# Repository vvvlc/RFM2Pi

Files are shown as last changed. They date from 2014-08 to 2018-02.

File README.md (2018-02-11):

# RFM2Pi
======



## RFM12B / RFM69CW to Raspberry Pi board

With the addition of an RFM12Pi expansion board to receive data via wireless from other [OpenEnergyMonitor modules](http://openenergymonitor.org/emon/Modules) such as an emonTx energy and temperature monitoring node or an emonGLCD display. A Raspberry Pi used to forward data to an emoncms sever or/and log data locally to a localy instance of Emoncms server running on the Pi.

# Hardware Design
For hardware designs see https://github.com/openenergymonitor/Hardware/tree/master/RFM2Pi

## Documentation Overview
http://openenergymonitor.org/emon/emonbase/raspberrypi

## Technial Wiki
http://wiki.openenergymonitor.org/index.php?title=RFM12Pi_V2

### The RFM12Pi is sold through the OpenEnergyMonitor shop:
http://shop.openenergymonitor.com/raspberry-pi/

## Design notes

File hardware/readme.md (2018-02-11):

## RFM2Pi

A collaboration between Martin Harizanov and OpenEnergyMonitor. Martin's origional repo: https://github.com/mharizanov/RFM2Pi/

### Schematic and board files: 

See board folder

### Schematic

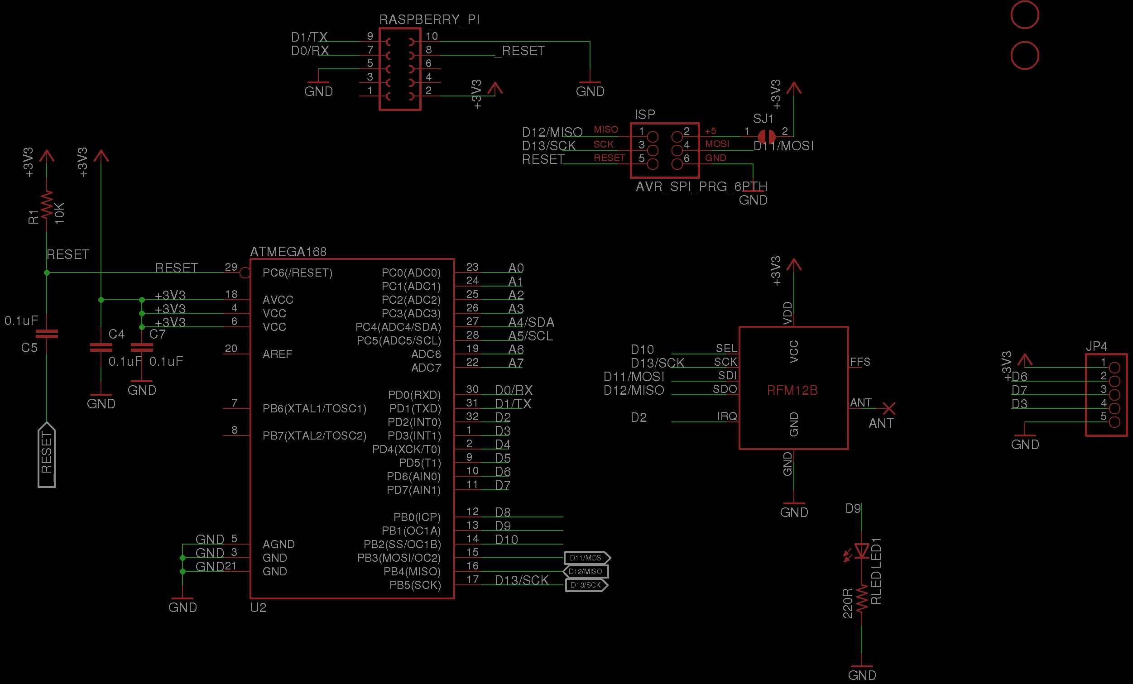
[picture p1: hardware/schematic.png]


Download schematic: [https://github.com/openenergymonitor/RFM2Pi/blob/master/board/v2/RFM2Pi_v2.6.sch](https://github.com/openenergymonitor/RFM2Pi/blob/master/board/v2/RFM2Pi_v2.6.sch)

### Board

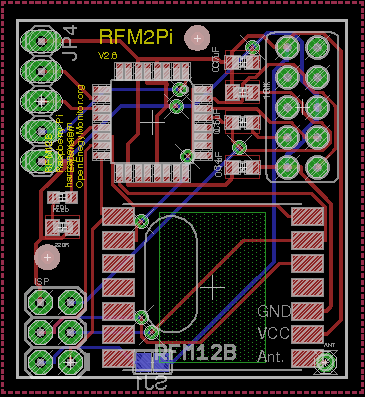
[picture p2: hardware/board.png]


Download board: [https://github.com/openenergymonitor/RFM2Pi/blob/master/board/v2/RFM2Pi_v2.6.brd](https://github.com/openenergymonitor/RFM2Pi/blob/master/board/v2/RFM2Pi_v2.6.brd)

### Open Hardware

Hardware designs (schematics and CAD) files are licensed under the [Creative Commons Attribution-ShareAlike 3.0 Unported License](http://creativecommons.org/licenses/by-sa/3.0/) and follow the terms of the [OSHW (Open-source hardware) Statement of Principles 1.0.](http://freedomdefined.org/OSHW)

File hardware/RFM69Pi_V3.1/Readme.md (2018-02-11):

## RFM2Pi V3

Updated RFM12B / RFM69CW expansion board for the Raspberry Pi with ATmega328 I/O broken out. Developed with help from [Ken Boak](http://sustburbia.blogspot.co.uk/) 

http://wiki.openenergymonitor.org/index.php?title=RFM69Pi_V3

### Board

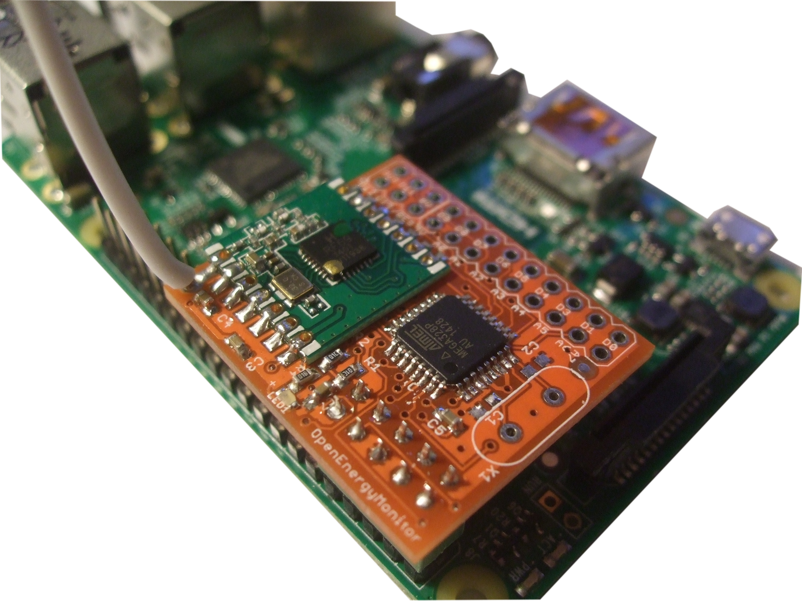
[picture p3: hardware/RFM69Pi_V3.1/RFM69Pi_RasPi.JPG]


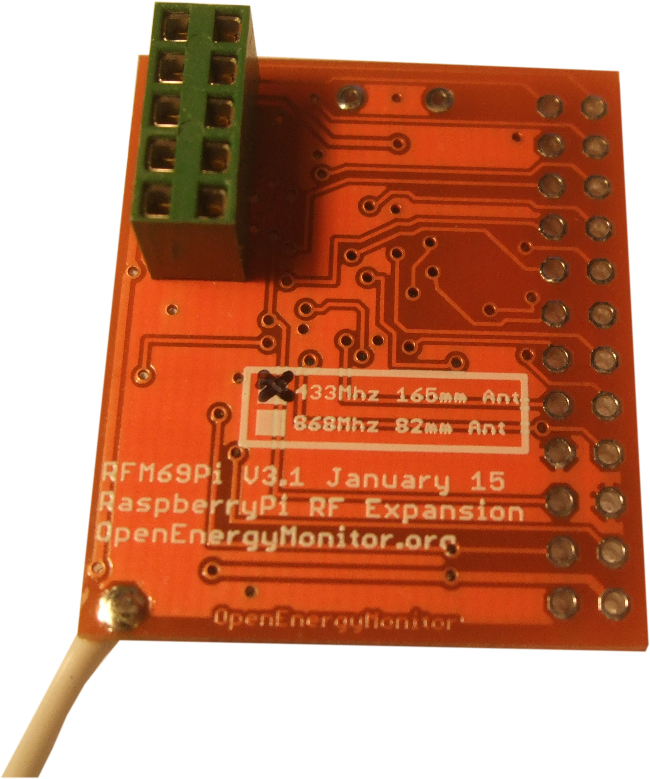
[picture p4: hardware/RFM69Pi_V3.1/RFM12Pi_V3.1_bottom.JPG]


### Schematic and board: 

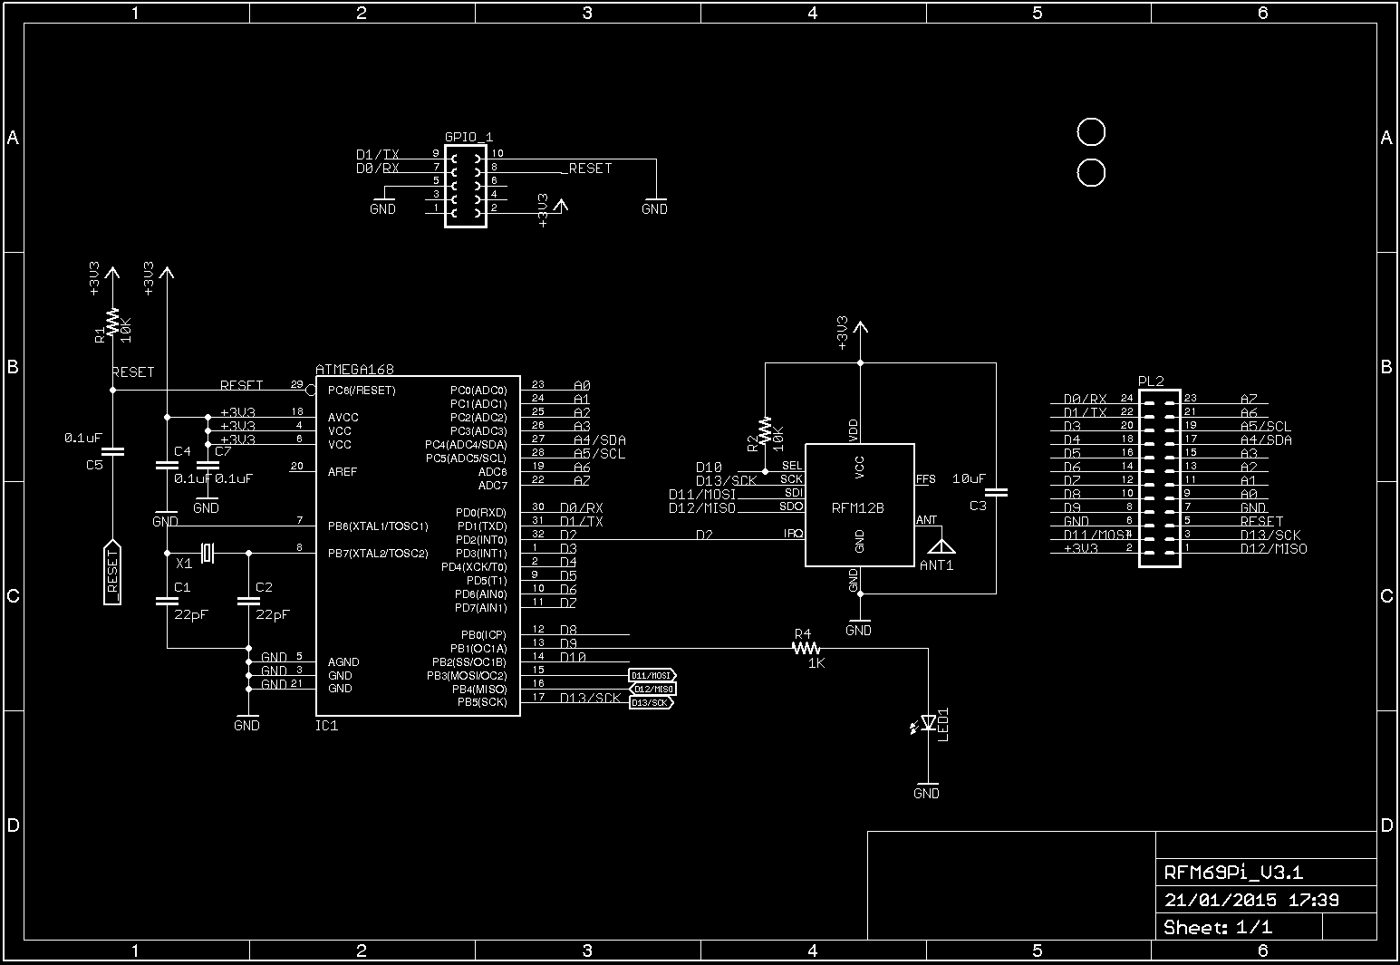
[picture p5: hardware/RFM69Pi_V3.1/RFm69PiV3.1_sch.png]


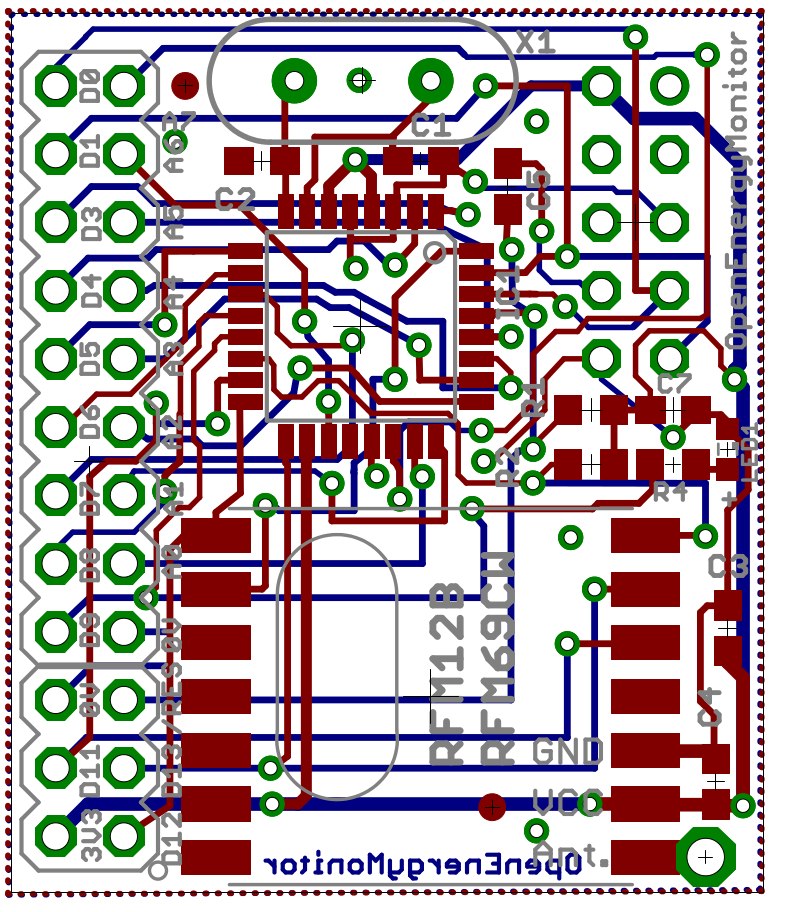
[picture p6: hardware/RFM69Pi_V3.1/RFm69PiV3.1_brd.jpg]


### Open Hardware

Hardware designs (schematics and CAD) files are licensed under the [Creative Commons Attribution-ShareAlike 3.0 Unported License](http://creativecommons.org/licenses/by-sa/3.0/) and follow the terms of the [OSHW (Open-source hardware) Statement of Principles 1.0.](http://freedomdefined.org/OSHW)

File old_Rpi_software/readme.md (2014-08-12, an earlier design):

old RFM12Pi software, emonHub is now used as our current (Aug 2014) RFM12Pi interface software

https://github.com/emonhub

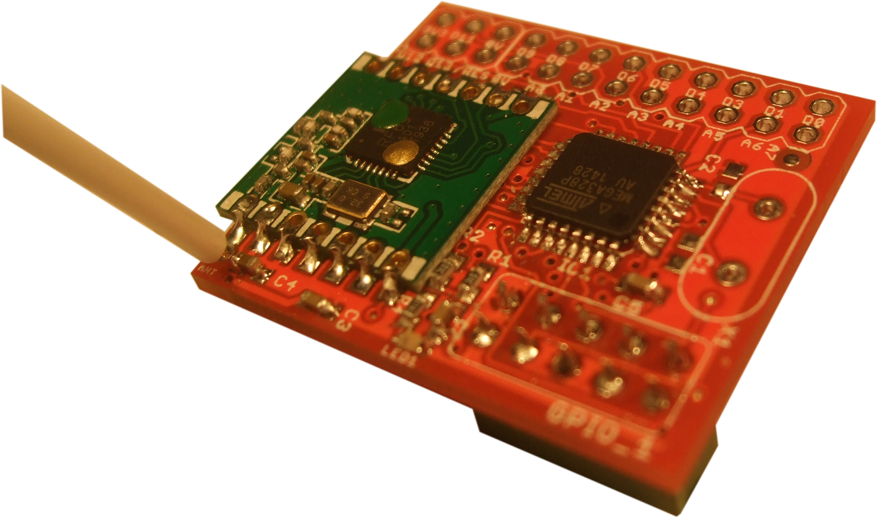
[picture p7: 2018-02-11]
hardware/RFM69Pi_V3.1/RFM12Pi_V3.1_top_side.JPG

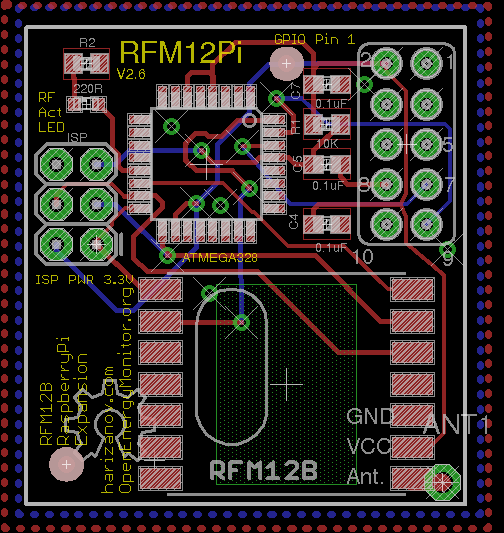
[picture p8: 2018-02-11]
hardware/RFM12Pi_V2.6/RFM12Pi_V2.6_brd.png

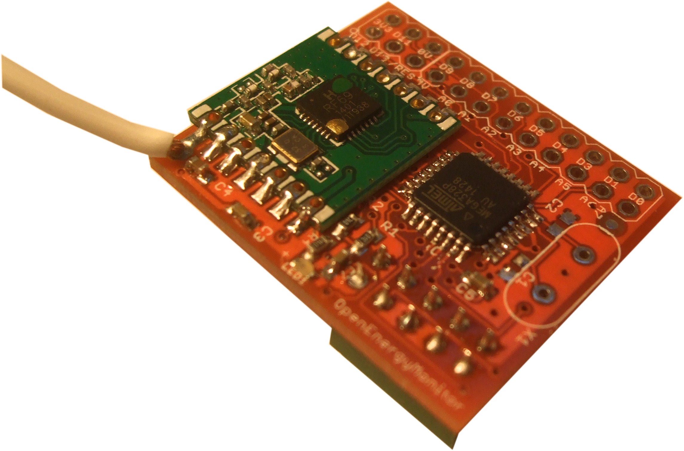
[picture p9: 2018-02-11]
hardware/RFM69Pi_V3.1/RFM12Pi_V3.1_top_side2.JPG

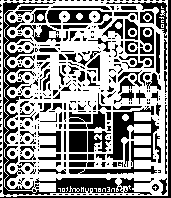
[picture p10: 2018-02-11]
hardware/RFM69Pi_V3.1/RFm69PiV3.1_brd_white.png

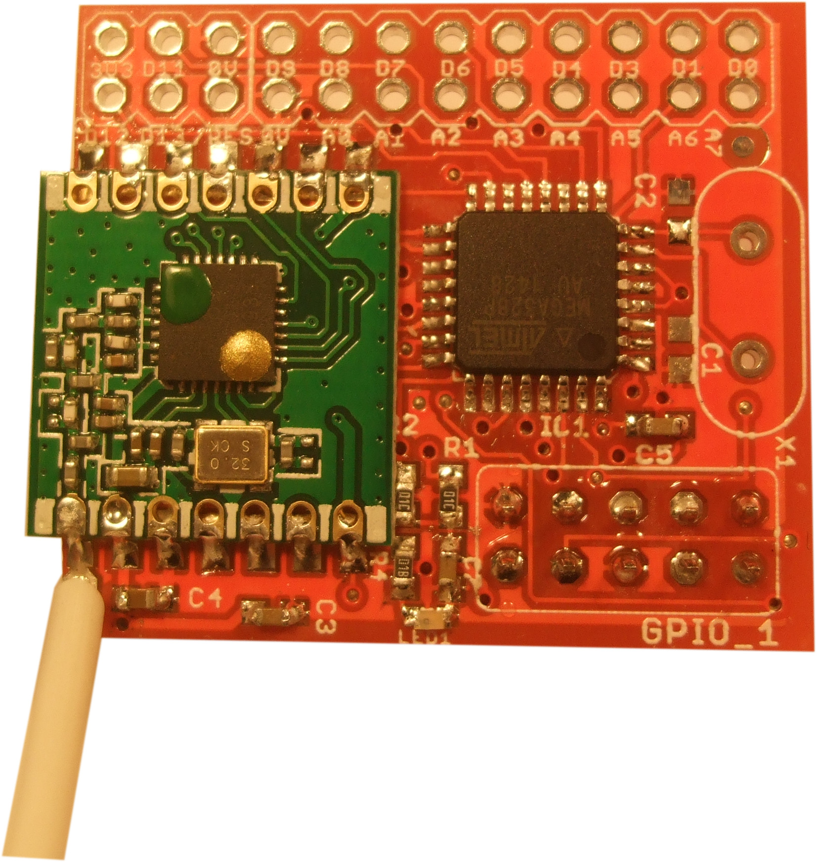
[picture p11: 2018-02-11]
hardware/RFM69Pi_V3.1/RFM12Pi_V3.1_top.JPG

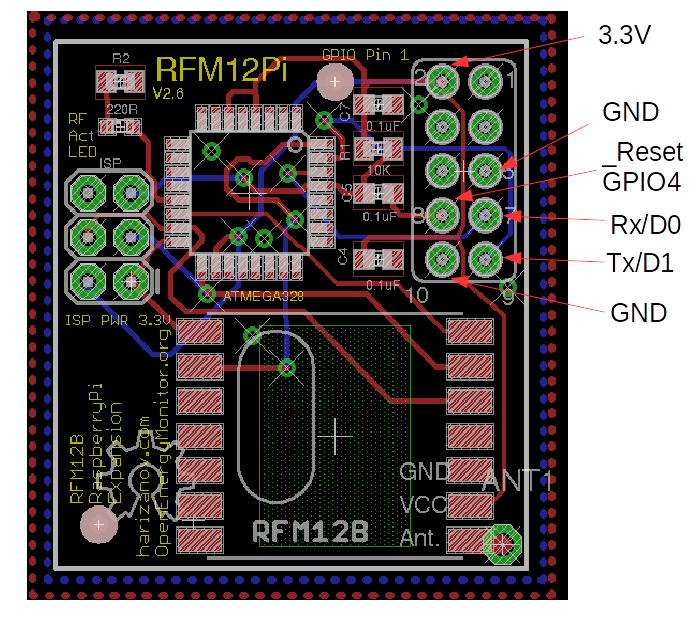
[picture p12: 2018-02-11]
hardware/RFM12Pi_V2.6/RFM12Pi_V1.6_pinout_brd.png

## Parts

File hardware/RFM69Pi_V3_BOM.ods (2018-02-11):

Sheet: DMT
 |  | RFM69Pi V3.1 1000PCS Feb 2015 |  |  |  |  | Megni / OpenEnergyMonitor – Glyn Hudson
Line No | Qty per | Parts | Value | Package | Order Qty | RS Part | Manufact | Manufact Part | Price Each | Line Price
 | SMT
1 | 3 | C4, C5, C7 | 100nF | 0603 | 3000 | 698-3320P | AVX | 0603YC104KAT2A | £0.01 | £21.00
2 | 2 | R1, R2 | 10K | 0603 | 2000 | 810-2094P | Panasonic | ERJ3RBD1002V | £0.01 | £18.00
3 | 1 | C3 | 10uF | 0603 | 1000 | 723-5543P | Murata | GRM188R60J106ME47D | £0.05 | £53.00
4 | 1 | R4 | 1K | R0603 | 1000 | 740-8791P | Bourns | CR0603-FX-1001ELF | £0.01 | £7.00
5 | 1 | LED1 | Red 1.85V | 0603 | 1000 | 654-5802P | OSRAM | LH Q974 | £0.02 | £24.00
6 | 1 | IC1 |  | TQFP32-08 | 1000 | 696-3092P | Atmel | ATMEGA328P-AU | £1.13 | £1,130.00
7 | 1 | X1 / GPIO_1 | 2 x 5 | 2.54mm female header | 1000 | 495-8644P | TE Connectivity | 215307-5 | 0.263 | £263.00 | INSERTED FROM REAR – SOLDERED ON TOP
 |  |  |  |  |  |  |  | Total | £1.49 | £1,253.00

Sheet: Megni Proc
Through Hole
800 | ANT | 165mm | 433mhz | 165mm 433Mhz / 82mm 868Mhz | PROCURED BY DAVID
200 | ANT | 82mm | 868mhz
Free issue by Megni – need to be placed but not procured
800 | RFM69CW | 433Mhz
200 | RFM69CW | 868Mhz
 | Exported from RFM69Pi CAD 27th Dec 2014

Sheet: BOM for Kaizen
 | RFM69Pi V3.1 1000PCS Feb 2015 |  |  |  |  | Megni / OpenEnergyMonitor – Glyn Hudson
Line No | Qty per | Parts | Value | Package | Order Qty | RS Part | Manufact | Manufact Part
1 | 3 | C4, C5, C7 | 100nF | 0603 | 3000 | 698-3320P | AVX | 0603YC104KAT2A
2 | 2 | R1, R2 | 10K | 0603 | 2000 | 810-2094P | Panasonic | ERJ3RBD1002V
3 | 1 | C3 | 10uF | 0603 | 1000 | 723-5543P | Murata | GRM188R60J106ME47D
4 | 1 | R4 | 1K | R0603 | 1000 | 740-8791P | Bourns | CR0603-FX-1001ELF
5 | 1 | LED1 | Red 1.85V | 0603 | 1000 | 654-5802P | OSRAM | LH Q974
6 | 1 | IC1 |  | TQFP32-08 | 1000 | 696-3092P | Atmel | ATMEGA328P-AU
7 | 1 | X1 / GPIO_1 | 2 x 5 | 2.54mm female header | 1000 | 495-8644P | TE Connectivity | 215307-5
8 | 1 | RFM69CW | 433Mhz | SMT | 800 | N/A | Hope RF | RFM69CW433
8 | 1 | RFM69CW | 868Mhz | SMT | 200 | N/A | Hope RF | RFM69CW868
9 | 1 | ANT | 165mm | 433mhz | 800 | Farnell 2343921 | Pro Wire | 4161 – PROCURED BY KAIZEN
9 | 1 | ANT | 82mm | 868mhz | 200 | Farnell 2343921 | Pro Wire | 4161 – PROCURED BY KAIZEN
 | updated 4th Feb 2015
 | RS Quote A1001654264
 | RS order 127992627 3rd Feb 2015

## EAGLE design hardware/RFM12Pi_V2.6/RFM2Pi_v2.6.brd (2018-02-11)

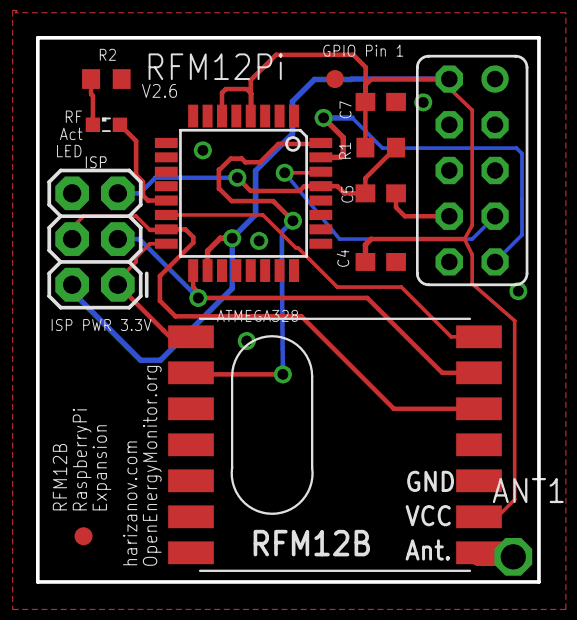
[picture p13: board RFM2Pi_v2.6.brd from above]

Board: 2 copper layers, 27.8 x 30.2 mm, 14 parts (1 on the bottom side), 14 nets.

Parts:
ANT1: PAD-01
C4, C5, C7: 0.1uF; C0603
ISP: AVR_SPI_PRG_6PTH; 2X3
LED: SML0603
R1: 10K; R0603
R2: 220R; R0603
RASPBERRY_PI: FE05-2
RFM12B: RFM12B
U2: ATMEGA168; TQFP32-08
U$1, U$2: FIDUCIAL; FIDUCIAL_1MM
U$4: OSHW_6X200_NOTEXT

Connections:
+3V3: C4.1, C7.1, ISP.2, R1.2, RASPBERRY_PI.2, RFM12B.VDD, U2.4, U2.6, U2.18
D0/RX: RASPBERRY_PI.7, U2.30
D1/TX: RASPBERRY_PI.9, U2.31
D2: RFM12B.IRQ, U2.32
D9: LED.A, U2.13
D10: RFM12B.SEL, U2.14
D11/MOSI: ISP.4, RFM12B.SDI, U2.15
D12/MISO: ISP.1, RFM12B.SDO, U2.16
D13/SCK: ISP.3, RFM12B.SCK, U2.17
GND: C4.2, C7.2, ISP.6, R2.1, RASPBERRY_PI.5, RASPBERRY_PI.10, RFM12B.GND, U2.3, U2.5, U2.21
unnamed: LED.C, R2.2
unnamed: ANT1.1, RFM12B.ANT
RESET: C5.2, ISP.5, R1.1, U2.29
_RESET: C5.1, RASPBERRY_PI.8

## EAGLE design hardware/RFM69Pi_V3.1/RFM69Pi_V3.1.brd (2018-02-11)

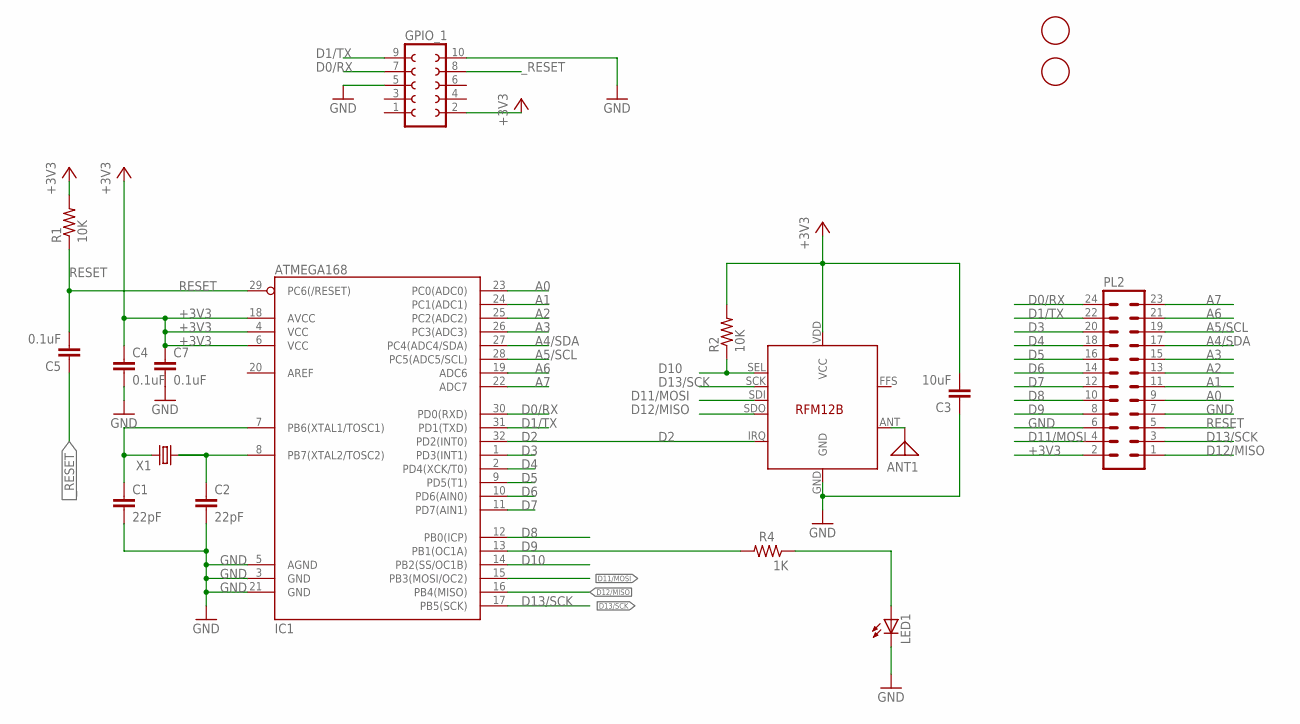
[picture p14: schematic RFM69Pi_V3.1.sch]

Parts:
ANT1: ANTENNA; PAD-01
C1, C2: 22pF; C0603
C3: 10uF; C0603
C4, C5, C7: 0.1uF; C0603
GPIO_1: FE05-2
IC1: ATMEGA168; TQFP32-08
LED1: LEDSML0603; SML0603
PL2: MA12-2
R1, R2: 10K; R0603
R4: 1K; R0603
RFM12B-RFM69CW: RFM12B
U$1, U$2: FIDUCIAL; FIDUCIAL_1MM
X1: CRYSTALHC49US; HC49US

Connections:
+3V3: C3.2, C4.1, C7.1, GPIO_1.2, IC1.4 (VCC), IC1.6 (VCC), IC1.18 (AVCC), PL2.2, R1.2, R2.2, RFM12B-RFM69CW.VDD (VCC)
A0: IC1.23 (PC0(ADC0)), PL2.9
A1: IC1.24 (PC1(ADC1)), PL2.11
A2: IC1.25 (PC2(ADC2)), PL2.13
A3: IC1.26 (PC3(ADC3)), PL2.15
A4/SDA: IC1.27 (PC4(ADC4/SDA)), PL2.17
A5/SCL: IC1.28 (PC5(ADC5/SCL)), PL2.19
A6: IC1.19 (ADC6), PL2.21
A7: IC1.22 (ADC7), PL2.23
D0/RX: GPIO_1.7, IC1.30 (PD0(RXD)), PL2.24
D1/TX: GPIO_1.9, IC1.31 (PD1(TXD)), PL2.22
D2: IC1.32 (PD2(INT0)), RFM12B-RFM69CW.IRQ
D3: IC1.1 (PD3(INT1)), PL2.20
D4: IC1.2 (PD4(XCK/T0)), PL2.18
D5: IC1.9 (PD5(T1)), PL2.16
D6: IC1.10 (PD6(AIN0)), PL2.14
D7: IC1.11 (PD7(AIN1)), PL2.12
D8: IC1.12 (PB0(ICP)), PL2.10
D9: IC1.13 (PB1(OC1A)), PL2.8, R4.2
D10: IC1.14 (PB2(SS/OC1B)), R2.1, RFM12B-RFM69CW.SEL
D11/MOSI: IC1.15 (PB3(MOSI/OC2)), PL2.4, RFM12B-RFM69CW.SDI
D12/MISO: IC1.16 (PB4(MISO)), PL2.1, RFM12B-RFM69CW.SDO
D13/SCK: IC1.17 (PB5(SCK)), PL2.3, RFM12B-RFM69CW.SCK
GND: C1.2, C2.2, C3.1, C4.2, C7.2, GPIO_1.5, GPIO_1.10, IC1.3 (GND), IC1.5 (AGND), IC1.21 (GND), LED1.C, PL2.6, PL2.7, RFM12B-RFM69CW.GND
unnamed: C1.1, IC1.7 (PB6(XTAL1/TOSC1)), X1.2
unnamed: C2.1, IC1.8 (PB7(XTAL2/TOSC2)), X1.1
unnamed: LED1.A, R4.1
unnamed: ANT1.1, RFM12B-RFM69CW.ANT
RESET: C5.2, IC1.29 (PC6(/RESET)), PL2.5, R1.1
_RESET: C5.1, GPIO_1.8

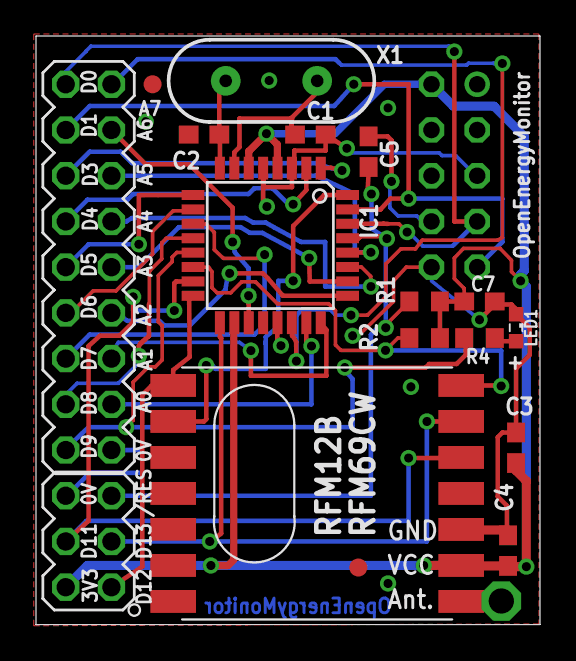
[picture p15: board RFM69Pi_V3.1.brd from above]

Board: 2 copper layers, 28.0 x 32.7 mm, 18 parts (0 on the bottom side), 30 nets.

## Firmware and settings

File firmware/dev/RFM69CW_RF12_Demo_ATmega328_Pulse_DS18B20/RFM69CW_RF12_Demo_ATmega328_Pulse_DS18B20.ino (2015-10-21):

//RFM12Pi V2 with RFM69CW Firmware 
//Based on JCW RF12 Demo: https://github.com/jcw/jeelib/tree/master/examples/RF12/RF12demo
//Edited for RFM12Pi and emonPi operation June 2014 by Glyn Hudson and Trystan Lea 
//http://OpenEnergyMonitor.org
//https://github.com/openenergymonitor/RFM2Pi

// V1.3 July 15 - add RF trace mode debug and fix node ID isse, merge pb66 pull requests 
  // https://github.com/openenergymonitor/RFM2Pi/pull/2
  // https://github.com/openenergymonitor/RFM2Pi/pull/4

// Version V1.0 - Nov 2014
// * 433Mhz default frequency, 15 default node ID

// V0.9 June 2014
// * 210 default network group
// * activity LED to light on startup and each time packet is received 

//--------------------------------------------------------------------------------------------------------------------------------------------

//------------------------------------------------------------------------
typedef struct {
    int pulsepower;
    unsigned long pulsecount; 
    int temp[6];  	                                      
} Payload;
Payload rfm2pi;
unsigned long lastdatasend = 0;

unsigned long pulsedebouncetime = 0;
unsigned long pulsetime = 0;
unsigned long lastpulsetime = 0;
unsigned long lastsentpulse = 0;
byte pulse_nodeid = 15;
int pulses_per_wh = 1;

// minimum width of interrupt pulse (default pulse output meters = 100ms)
const byte min_pulsewidth= 110;

//------------------------------------------------------------------------

/// @dir RF12demo
/// Configure some values in EEPROM for easy config of the RF12 later on.
// 2009-05-06 <jc@wippler.nl> http://opensource.org/licenses/mit-license.php

// this version adds flash memory support, 2009-11-19
// Adding frequency features, author JohnO, 2013-09-05
// Major EEPROM format change, refactoring, and cleanup for v12, 2014-02-13

#define RF69_COMPAT 1 // define this to use the RF69 driver i.s.o. RF12

#include <JeeLib.h>
#include <util/crc16.h>
#include <avr/eeprom.h>
#include <avr/pgmspace.h>
#include <util/parity.h>

#define MAJOR_VERSION RF12_EEPROM_VERSION // bump when EEPROM layout changes
#define MINOR_VERSION 2                   // bump on other non-trivial changes
#define VERSION "[RF12demo.13]"           // keep in sync with the above

#if defined(__AVR_ATtiny84__) || defined(__AVR_ATtiny44__)
#define TINY        1
#define SERIAL_BAUD 38400   // can only be 9600 or 38400
#define DATAFLASH   0       // do not change
#undef  LED_PIN             // do not change
#define rf12_configDump()   // disabled
#else
#define TINY        0
#define SERIAL_BAUD 38400   // max baud for 8Mhz RFM12Pi http://openenergymonitor.org/emon/node/6244/
#define DATAFLASH   0       // set to 0 for non-JeeLinks, else 4/8/16 (Mbit)
#define LED_PIN     9       // activity LED, comment out to disable
#endif

/// Save a few bytes of flash by declaring const if used more than once.
const char INVALID1[] PROGMEM = "\rInvalid\n";
const char INITFAIL[] PROGMEM = "config save failed\n";

#if RF69_COMPAT
  byte trace_mode = 0;
#endif

#if TINY
// Serial support (output only) for Tiny supported by TinyDebugSerial
// http://www.ernstc.dk/arduino/tinycom.html
// 9600, 38400, or 115200
// hardware\jeelabs\avr\cores\tiny\TinyDebugSerial.h Modified to
// moveTinyDebugSerial from PB0 to PA3 to match the Jeenode Micro V3 PCB layout
// Connect Tiny84 PA3 to USB-BUB RXD for serial output from sketch.
// Jeenode AIO2
//
// With thanks for the inspiration by 2006 David A. Mellis and his AFSoftSerial
// code. All right reserved.
// Connect Tiny84 PA2 to USB-BUB TXD for serial input to sketch.
// Jeenode DIO2
// 9600 or 38400 at present.

#if SERIAL_BAUD == 9600
#define BITDELAY 54          // 9k6 @ 8MHz, 19k2 @16MHz
#endif
#if SERIAL_BAUD == 38400
#define BITDELAY 11         // 38k4 @ 8MHz, 76k8 @16MHz
#endif

#define _receivePin 8
static int _bitDelay;
static char _receive_buffer;
static byte _receive_buffer_index;

ISR (PCINT0_vect) {
  char i, d = 0;
  if (digitalRead(_receivePin))       // PA2 = Jeenode DIO2
    return;             // not ready!
  whackDelay(_bitDelay - 8);
  for (i=0; i<8; i++) {
    whackDelay(_bitDelay*2 - 6);    // digitalread takes some time
    if (digitalRead(_receivePin)) // PA2 = Jeenode DIO2
      d |= (1 << i);
  }
  whackDelay(_bitDelay*2);
  if (_receive_buffer_index)
    return;
  _receive_buffer = d;                // save data
  _receive_buffer_index = 1;  // got a byte
}

// TODO: replace with code from the std avr libc library:
//  http://www.nongnu.org/avr-libc/user-manual/group__util__delay__basic.html
void whackDelay (word delay) {
  byte tmp=0;

  asm volatile("sbiw      %0, 0x01 \n\t"
    "ldi %1, 0xFF \n\t"
    "cpi %A0, 0xFF \n\t"
    "cpc %B0, %1 \n\t"
    "brne .-10 \n\t"
: 
    "+r" (delay), "+a" (tmp)
: 
    "0" (delay)
    );
}

static byte inChar () {
  byte d;
  if (! _receive_buffer_index)
    return -1;
  d = _receive_buffer; // grab first and only byte
  _receive_buffer_index = 0;
  return d;
}

#endif

static unsigned long now () {
  // FIXME 49-day overflow
  return millis() / 1000;
}

static void activityLed (byte on) {
#ifdef LED_PIN
  pinMode(LED_PIN, OUTPUT);
  digitalWrite(LED_PIN, on);
#endif
}

static void printOneChar (char c) {
  Serial.print(c);
}

/// @details
/// For the EEPROM layout, see http://jeelabs.net/projects/jeelib/wiki/RF12demo
/// Useful url: http://blog.strobotics.com.au/2009/07/27/rfm12-tutorial-part-3a/

// RF12 configuration area
typedef struct {
  byte nodeId;            // used by rf12_config, offset 0
  byte group;             // used by rf12_config, offset 1
  byte format;            // used by rf12_config, offset 2
byte hex_output   :
  2;   // 0 = dec, 1 = hex, 2 = hex+ascii
byte collect_mode :
  1;   // 0 = ack, 1 = don't send acks
byte quiet_mode   :
  1;   // 0 = show all, 1 = show only valid packets
byte spare_flags  :
  4;
  word frequency_offset;  // used by rf12_config, offset 4
  byte pad[RF12_EEPROM_SIZE-8];
  word crc;
} 
RF12Config;

static RF12Config config;
static char cmd;
static word value;
static byte stack[RF12_MAXDATA+4], top, sendLen, dest;
static byte testCounter;

static void showNibble (byte nibble) {
  char c = '0' + (nibble & 0x0F);
  if (c > '9')
    c += 7;
  Serial.print(c);
}

static void showByte (byte value) {
  if (config.hex_output) {
    showNibble(value >> 4);
    showNibble(value);
  } 
  else
    Serial.print((word) value);
}

static word calcCrc (const void* ptr, byte len) {
  word crc = ~0;
  for (byte i = 0; i < len; ++i)
    crc = _crc16_update(crc, ((const byte*) ptr)[i]);
  return crc;
}

static void loadConfig () {
  // eeprom_read_block(&config, RF12_EEPROM_ADDR, sizeof config);
  // this uses 166 bytes less flash than eeprom_read_block(), no idea why
  for (byte i = 0; i < sizeof config; ++ i)
    ((byte*) &config)[i] = eeprom_read_byte(RF12_EEPROM_ADDR + i);
}

static void saveConfig () {
  config.format = MAJOR_VERSION;
  config.crc = calcCrc(&config, sizeof config - 2);
  // eeprom_write_block(&config, RF12_EEPROM_ADDR, sizeof config);
  // this uses 170 bytes less flash than eeprom_write_block(), no idea why
  eeprom_write_byte(RF12_EEPROM_ADDR, ((byte*) &config)[0]);
  for (byte i = 0; i < sizeof config; ++ i)
    eeprom_write_byte(RF12_EEPROM_ADDR + i, ((byte*) &config)[i]);

  if (rf12_configSilent())
    rf12_configDump();
  else
    showString(INITFAIL);
}

static byte bandToFreq (byte band) {
  return band == 4 ? RF12_433MHZ : band == 8 ? RF12_868MHZ : band == 9 ? RF12_915MHZ : 0;
}

// - - - - - - - - - - - - - - - - - - - - - - - - - - - - - - - - - - - - - - -
// OOK transmit code

#if RF69_COMPAT // not implemented in RF69 compatibility mode
static void fs20cmd(word house, byte addr, byte cmd) {
}
static void kakuSend(char addr, byte device, byte on) {
}
#else

// Turn transmitter on or off, but also apply asymmetric correction and account
// for 25 us SPI overhead to end up with the proper on-the-air pulse widths.
// With thanks to JGJ Veken for his help in getting these values right.
static void ookPulse(int on, int off) {
  rf12_onOff(1);
  delayMicroseconds(on + 150);
  rf12_onOff(0);
  delayMicroseconds(off - 200);
}

static void fs20sendBits(word data, byte bits) {
  if (bits == 8) {
    ++bits;
    data = (data << 1) | parity_even_bit(data);
  }
  for (word mask = bit(bits-1); mask != 0; mask >>= 1) {
    int width = data & mask ? 600 : 400;
    ookPulse(width, width);
  }
}

static void fs20cmd(word house, byte addr, byte cmd) {
  byte sum = 6 + (house >> 8) + house + addr + cmd;
  for (byte i = 0; i < 3; ++i) {
    fs20sendBits(1, 13);
    fs20sendBits(house >> 8, 8);
    fs20sendBits(house, 8);
    fs20sendBits(addr, 8);
    fs20sendBits(cmd, 8);
    fs20sendBits(sum, 8);
    fs20sendBits(0, 1);
    delay(10);
  }
}

static void kakuSend(char addr, byte device, byte on) {
  int cmd = 0x600 | ((device - 1) << 4) | ((addr - 1) & 0xF);
  if (on)
    cmd |= 0x800;
  for (byte i = 0; i < 4; ++i) {
    for (byte bit = 0; bit < 12; ++bit) {
      ookPulse(375, 1125);
      int on = bitRead(cmd, bit) ? 1125 : 375;
      ookPulse(on, 1500 - on);
    }
    ookPulse(375, 375);
    delay(11); // approximate
  }
}

#endif

// - - - - - - - - - - - - - - - - - - - - - - - - - - - - - - - - - - - - - - -
// DataFlash code

#if DATAFLASH
#include "dataflash.h"
#else // DATAFLASH

#define df_present() 0
#define df_initialize()
#define df_dump()
#define df_replay(x,y)
#define df_erase(x)
#define df_wipe()
#define df_append(x,y)

#endif

// - - - - - - - - - - - - - - - - - - - - - - - - - - - - - - - - - - - - - - -

const char helpText1[] PROGMEM =
"\n"
"Available commands:\n"
"  <nn> i     - set node ID (standard node ids are 1..30)\n"
"  <n> b      - set MHz band (4 = 433, 8 = 868, 9 = 915)\n"
"  <nnnn> o   - change frequency offset within the band (default 1600)\n"
"               96..3903 is the range supported by the RFM12B\n"
"  <nnn> g    - set network group (RFM12 only allows 212, 0 = any)\n"
"  <n> c      - set collect mode (advanced, normally 0)\n"
"  t          - broadcast max-size test packet, request ack\n"
"  ...,<nn> a - send data packet to node <nn>, request ack\n"
"  ...,<nn> s - send data packet to node <nn>, no ack\n"
"  <n> q      - set quiet mode (1 = don't report bad packets)\n"
"  <n> x      - set reporting format (0: decimal, 1: hex, 2: hex+ascii)\n"
#if RF69_COMPAT
"  <nnn> y    - enable signal strength trace mode, default:0 (disabled)\n"
"               sample interval <nnn> secs/100 (0.01s-2.5s) eg 10y=0.1s\n"
#endif
"  123 z      - total power down, needs a reset to start up again\n"
"Remote control commands:\n"
"  <hchi>,<hclo>,<addr>,<cmd> f     - FS20 command (868 MHz)\n"
"  <addr>,<dev>,<on> k              - KAKU command (433 MHz)\n"
;

const char helpText2[] PROGMEM =
"Flash storage (JeeLink only):\n"
"    d                                  - dump all log markers\n"
"    <sh>,<sl>,<t3>,<t2>,<t1>,<t0> r    - replay from specified marker\n"
"    123,<bhi>,<blo> e                  - erase 4K block\n"
"    12,34 w                            - wipe entire flash memory\n"
;

static void showString (PGM_P s) {
  for (;;) {
    char c = pgm_read_byte(s++);
    if (c == 0)
      break;
    if (c == '\n')
      printOneChar('\r');
    printOneChar(c);
  }
}

static void showHelp () {
#if TINY
  showString(PSTR("?\n"));
#else
  showString(helpText1);
  if (df_present())
    showString(helpText2);
  showString(PSTR("Current configuration:\n"));
  rf12_configDump();
#endif
}

static void handleInput (char c) {
  if ('0' <= c && c <= '9') {
    value = 10 * value + c - '0';
    return;
  }

  if (c == ',') {
    if (top < sizeof stack)
      stack[top++] = value; // truncated to 8 bits
    value = 0;
    return;
  }

  if ('a' <= c && c <= 'z') {
    showString(PSTR("> "));
    for (byte i = 0; i < top; ++i) {
      Serial.print((word) stack[i]);
      printOneChar(',');
    }
    Serial.print(value);
    Serial.println(c);
  }

  // keeping this out of the switch reduces code size (smaller branch table)
  if (c == '>') {
    // special case, send to specific band and group, and don't echo cmd
    // input: band,group,node,header,data...
    stack[top++] = value;
    // TODO: frequency offset is taken from global config, is that ok?
    rf12_initialize(stack[2], bandToFreq(stack[0]), stack[1],
    config.frequency_offset);
    rf12_sendNow(stack[3], stack + 4, top - 4);
    rf12_sendWait(2);
    rf12_configSilent();
  } 
  else if (c > ' ') {
    switch (c) {

    case 'i': // set node id
      if ((value > 0) && (value < 31)) {
        config.nodeId = (config.nodeId & 0xE0) + (value & 0x1F);
        saveConfig();
        }
      break;

    case 'b': // set band: 4 = 433, 8 = 868, 9 = 915
      value = bandToFreq(value);
      if (value) {
        config.nodeId = (value << 6) + (config.nodeId & 0x3F);
        config.frequency_offset = 1600;
        saveConfig();
      }
      break;

    case 'o': 
      { // Increment frequency within band
        // Stay within your country's ISM spectrum management guidelines, i.e.
        // allowable frequencies and their use when selecting operating frequencies.
        if ((value > 95) && (value < 3904)) { // supported by RFM12B
          config.frequency_offset = value;
          saveConfig();
        }
#if !TINY
        // this code adds about 400 bytes to flash memory use
        // display the exact frequency associated with this setting
        byte freq = 0, band = config.nodeId >> 6;
        switch (band) {
        case RF12_433MHZ: 
          freq = 43; 
          break;
        case RF12_868MHZ: 
          freq = 86; 
          break;
        case RF12_915MHZ: 
          freq = 90; 
          break;
        }
        uint32_t f1 = freq * 100000L + band * 25L * config.frequency_offset;
        Serial.print((word) (f1 / 10000));
        printOneChar('.');
        word f2 = f1 % 10000;
        // tedious, but this avoids introducing floating point
        printOneChar('0' + f2 / 1000);
        printOneChar('0' + (f2 / 100) % 10);
        printOneChar('0' + (f2 / 10) % 10);
        printOneChar('0' + f2 % 10);
        Serial.println(" MHz");
#endif
        break;
      }

    case 'g': // set network group
      config.group = value;
      saveConfig();
      break;

    case 'c': // set collect mode (off = 0, on = 1)
      config.collect_mode = value;
      saveConfig();
      break;

    case 't': // broadcast a maximum size test packet, request an ack
      cmd = 'a';
      sendLen = RF12_MAXDATA;
      dest = 0;
      for (byte i = 0; i < RF12_MAXDATA; ++i)
        stack[i] = i + testCounter;
      showString(PSTR("test "));
      showByte(testCounter); // first byte in test buffer
      ++testCounter;
      break;

    case 'a': // send packet to node ID N, request an ack
    case 's': // send packet to node ID N, no ack
      cmd = c;
      sendLen = top;
      dest = value;
      break;

    case 'f': // send FS20 command: <hchi>,<hclo>,<addr>,<cmd>f
      rf12_initialize(0, RF12_868MHZ, 0);
      activityLed(1);
      fs20cmd(256 * stack[0] + stack[1], stack[2], value);
      activityLed(0);
      rf12_configSilent();
      break;

    case 'k': // send KAKU command: <addr>,<dev>,<on>k
      rf12_initialize(0, RF12_433MHZ, 0);
      activityLed(1);
      kakuSend(stack[0], stack[1], value);
      activityLed(0);
      rf12_configSilent();
      break;

    case 'z': // put the ATmega in ultra-low power mode (reset needed)
      if (value == 123) {
        showString(PSTR(" Zzz...\n"));
        Serial.flush();
        rf12_sleep(RF12_SLEEP);
        cli();
        Sleepy::powerDown();
      }
      break;

    case 'q': // turn quiet mode on or off (don't report bad packets)
      config.quiet_mode = value;
      saveConfig();
      break;

    case 'x': // set reporting mode to decimal (0), hex (1), hex+ascii (2)
      config.hex_output = value;
      saveConfig();
      break;

    case 'v': //display the interpreter version and configuration
      displayVersion();
      rf12_configDump();
#if TINY
      Serial.println();
#endif
      break;

      // the following commands all get optimised away when TINY is set

    case 'l': // turn activity LED on or off
      activityLed(value);
      break;

    case 'd': // dump all log markers
      if (df_present())
        df_dump();
      break;

    case 'r': // replay from specified seqnum/time marker
      if (df_present()) {
        word seqnum = (stack[0] << 8) | stack[1];
        long asof = (stack[2] << 8) | stack[3];
        asof = (asof << 16) | ((stack[4] << 8) | value);
        df_replay(seqnum, asof);
      }
      break;

    case 'e': // erase specified 4Kb block
      if (df_present() && stack[0] == 123) {
        word block = (stack[1] << 8) | value;
        df_erase(block);
      }
      break;

    case 'w': // wipe entire flash memory
      if (df_present() && stack[0] == 12 && value == 34) {
        df_wipe();
        showString(PSTR("erased\n"));
      }
      break;
#if RF69_COMPAT
    case 'y': // turn signal strength trace mode on or off (rfm69 only)
      trace_mode = value;
      break;
#endif

    default:
      showHelp();
    }
  }

  value = top = 0;
}

static void displayASCII (const byte* data, byte count) {
  for (byte i = 0; i < count; ++i) {
    printOneChar(' ');
    char c = (char) data[i];
    printOneChar(c < ' ' || c > '~' ? '.' : c);
  }
  Serial.println();
}

static void displayVersion () {
  showString(PSTR(VERSION));
#if TINY
  showString(PSTR(" Tiny"));
#endif
}

void setup () {
  activityLed(1);
  delay(100); // shortened for now. Handy with JeeNode Micro V1 where ISP
  // interaction can be upset by RF12B startup process.

#if TINY
  PCMSK0 |= (1<<PCINT2);  // tell pin change mask to listen to PA2
  GIMSK |= (1<<PCIE0);    // enable PCINT interrupt in general interrupt mask
  // FIXME: _bitDelay has not yet been initialised here !?
  whackDelay(_bitDelay*2); // if we were low this establishes the end
  pinMode(_receivePin, INPUT);        // PA2
  digitalWrite(_receivePin, HIGH);    // pullup!
  _bitDelay = BITDELAY;
#endif

  Serial.begin(SERIAL_BAUD);
  Serial.println();
  displayVersion();

  if (rf12_configSilent()) {
    loadConfig();
  } 
  else {
    memset(&config, 0, sizeof config);
   config.nodeId = 0x4F;                           // RFM12Pi - 433 MHz, node 15
    config.group = 0xD2;                           // RFM12Pi - default group 210
    config.frequency_offset = 1600;
    config.quiet_mode = true;   // Default flags, quiet on
    saveConfig();
    rf12_configSilent();
  }

  rf12_configDump();
  df_initialize();
#if !TINY
  showHelp();
#endif

  delay(1000);        //rfm12pi keep LED for for 1s to show it's working at startup 
  activityLed(0);
  
  DS18B20_setup();
  
  attachInterrupt(1, onPulse, FALLING);
}

void loop () {

  if ((millis()-lastdatasend)>5000) {
      lastdatasend = millis();
      
      DS18B20_readall();
      delay(100);
      send_as_rf12_demo_packet();
      delay(100);
  }
  
#if TINY
  if (_receive_buffer_index)
    handleInput(inChar());
#else
  if (Serial.available())
    handleInput(Serial.read());
#endif
#if RF69_COMPAT
  if (trace_mode == 0) {
#endif
  if (rf12_recvDone()) {
    byte n = rf12_len;
    if (rf12_crc == 0)
    {
      activityLed(1);
      showString(PSTR("OK"));
    }
    else {
      if (config.quiet_mode)
        return;
      showString(PSTR(" ?"));
      if (n > 20) // print at most 20 bytes if crc is wrong
        n = 20;
    }
    if (config.hex_output)
      printOneChar('X');
    if (config.group == 0) {
      showString(PSTR(" G"));
      showByte(rf12_grp);
    }
    printOneChar(' ');
    showByte(rf12_hdr & 0x1F);
    for (byte i = 0; i < n; ++i) {
      if (!config.hex_output)
        printOneChar(' ');
      showByte(rf12_data[i]);
    }
#if RF69_COMPAT
    // display RSSI value after packet data
    showString(PSTR(" ("));
    if (config.hex_output)
      showByte(RF69::rssi);
    else
      Serial.print(-(RF69::rssi>>1));
    showString(PSTR(") "));
#endif
    Serial.println();

    if (config.hex_output > 1) { // also print a line as ascii
      showString(PSTR("ASC "));
      if (config.group == 0) {
        showString(PSTR(" II "));
      }
      printOneChar(rf12_hdr & RF12_HDR_DST ? '>' : '<');
      printOneChar('@' + (rf12_hdr & RF12_HDR_MASK));
      displayASCII((const byte*) rf12_data, n);
    }

    if (rf12_crc == 0) {
      activityLed(1);

      if (df_present())
        df_append((const char*) rf12_data - 2, rf12_len + 2);

      if (RF12_WANTS_ACK && (config.collect_mode) == 0) {
        showString(PSTR(" -> ack\n"));
        rf12_sendStart(RF12_ACK_REPLY, 0, 0);
      }
      activityLed(0);
    }
  }

  if (cmd && rf12_canSend()) {
    activityLed(1);

    showString(PSTR(" -> "));
    Serial.print((word) sendLen);
    showString(PSTR(" b\n"));
    byte header = cmd == 'a' ? RF12_HDR_ACK : 0;
    if (dest)
      header |= RF12_HDR_DST | dest;
    rf12_sendStart(header, stack, sendLen);
    cmd = 0;

    activityLed(0);
  }
  activityLed(0);
#if RF69_COMPAT      
  } else {
      rf12_recvDone();
      byte y = (RF69::rssi>>1);
      for (byte i = 0; i < (100-y); ++i) {
          printOneChar('-');
      }
      Serial.print("*");
      for (byte i = 0; i < (y); ++i) {
          printOneChar(' ');
      }
      Serial.print(-y);
      Serial.println("dB");
      
      delay(trace_mode*10);
      
  }   
#endif
}

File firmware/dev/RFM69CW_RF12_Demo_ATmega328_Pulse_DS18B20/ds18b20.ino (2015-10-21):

#include <OneWire.h>                                                             // http://www.pjrc.com/teensy/td_libs_OneWire.html
#include <DallasTemperature.h>                                                   // http://download.milesburton.com/Arduino/MaximTemperature/DallasTemperature_LATEST.zip

#define ONEWIRE_MAX              6
#define ONEWIRE_BUS              5
#define TEMPERATURE_PRECISION    11

// Conversion time:
// 9bit:95ms, 10bit:187ms, 11bit:375ms, 12bit:750ms
#define ASYNC_DELAY              375

OneWire oneWire(ONEWIRE_BUS);
DallasTemperature sensors(&oneWire);
byte sensor_address [ONEWIRE_MAX][8];  // 8 bytes per address
byte numSensors;

void DS18B20_setup()
{
  sensors.begin();
  sensors.setWaitForConversion(false);
  numSensors = sensors.getDeviceCount();
  if (numSensors > ONEWIRE_MAX) numSensors = ONEWIRE_MAX;
  
  byte j = 0;
  while ((j < numSensors) && (oneWire.search(sensor_address[j]))) j++;
}

void DS18B20_readall()
{
  for(int j = 0;j<numSensors;j++) {
    sensors.setResolution(sensor_address[j], TEMPERATURE_PRECISION);
  }
  
  sensors.requestTemperatures();
  delay(ASYNC_DELAY);
  
  for(byte j=0;j<numSensors;j++) {
    rfm2pi.temp[j] = sensors.getTempC(sensor_address[j]) * 100;
  }
}

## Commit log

2014-10-27 add Kicad version
    [KiCad_test.kicad_pcb, KiCad_test.sch]
2014-11-13 remove hardware from software repo
    [KiCad_test.kicad_pcb, KiCad_test.sch, RFM2Pi_rev3.brd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]
2014-12-18 bugfix for ack effecting node id
    http://openenergymonitor.org/emon/node/6244
    [RFM69CW_RF12_Demo_ATmega328.ino]
2015-07-10 qualify command 'i' value before setting node id
    A stray "i" can attempt to set a node id of "0" and result in a "config save failed" although setting the node id to "0" will of succeeded and the result is no further packets will be processed until a valid node id is set.
    [RFM69CW_RF12_Demo_ATmega328.ino]
2015-07-10 added a "trace_mode" to debug rf issues
    [RFM69CW_RF12_Demo_ATmega328.ino]
2015-10-21 compiled with correct board version
2016-03-06 added upload atmega328_384_8.upload.tool and atmega328_384_8.build.board
2016-12-09 remove attiny code and fix compile
    [src.ino]
2017-03-10 add hardware
    [RFM2Pi_v2.6.brd, RFM2Pi_v2.6.sch, RFM69Pi_V3.1.brd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]
